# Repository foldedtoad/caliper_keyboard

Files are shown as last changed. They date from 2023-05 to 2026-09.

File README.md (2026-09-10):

# Caliper Keyboard - Digital Caliper Data Over Bluetooth (HOG)

## Overview
This poject's goal is to provide a remote interface to the various cheap Digital Calipers.  
This project's firmware is being developed on Zephyr Version 4.4.99.  
This is a major Zephyr upgrade and breaks backwards compatibility.

The Nordic nRF52 series Developemt Kits are the target hardware platform: PCA10056 (nRF52840dk_nrf52840) and a new custom board (**"nrf52840_caliper"**).
The nordic PCA10056 board was use for early development; there will be new board, nrf52840_caliper, specifically designed to be affixed to the back of a caliper.

Go to this project's [**Wiki**](https://github.com/foldedtoad/caliper_keyboard/wiki) page for more details.  

The image below shows size of the  **nrf52840_caliper** board, which is sized to fit on the back of calipers.  

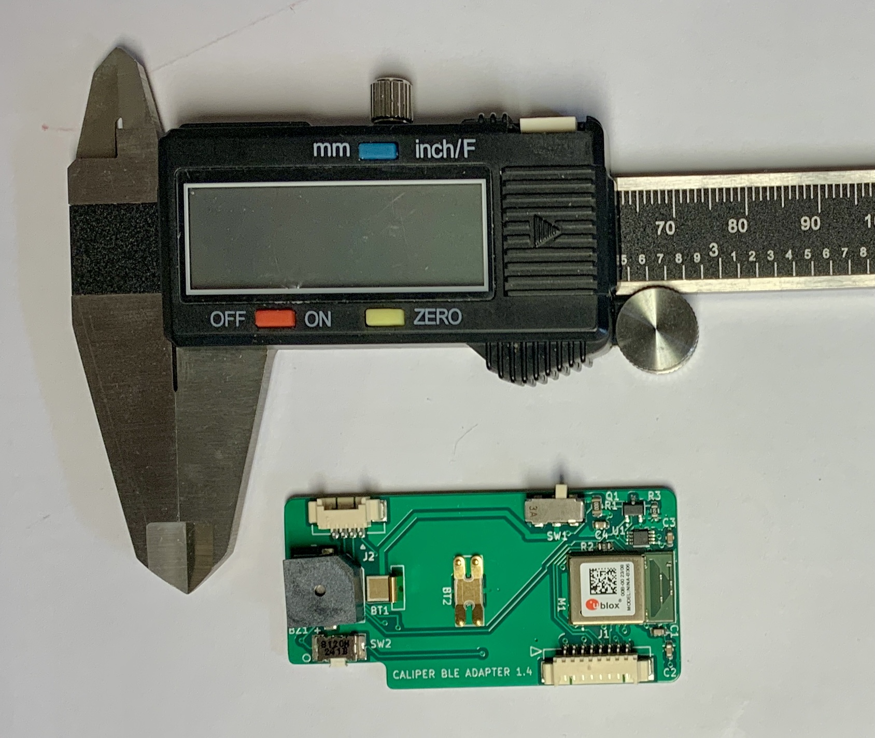
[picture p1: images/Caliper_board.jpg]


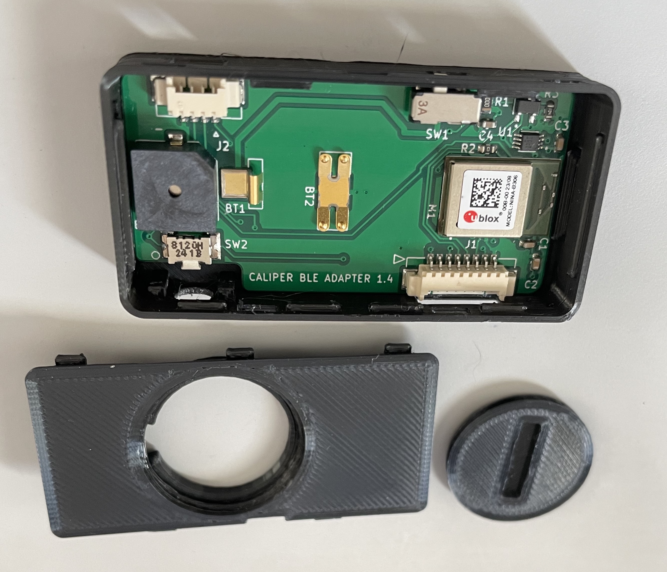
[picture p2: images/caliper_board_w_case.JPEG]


## Video of Caliper_Keyboard
There is a youtube video showing the caliper_keyboard attached to a cheap caliper: https://youtu.be/K_FeKUWlJKM

## How to Build
There are two easy methods to build the firmware.

### CMake Method
This build method use cmake directly, and doesn't use west or ninja.
1) cd to your caliper_keyboard root directory
2) run "./configure.sh"
3) cd to build directory
4) make

### West Method
1) cd to your caliper_keyboard root directory
2) rm -rf build
3) west build -b nrf52840_caliper

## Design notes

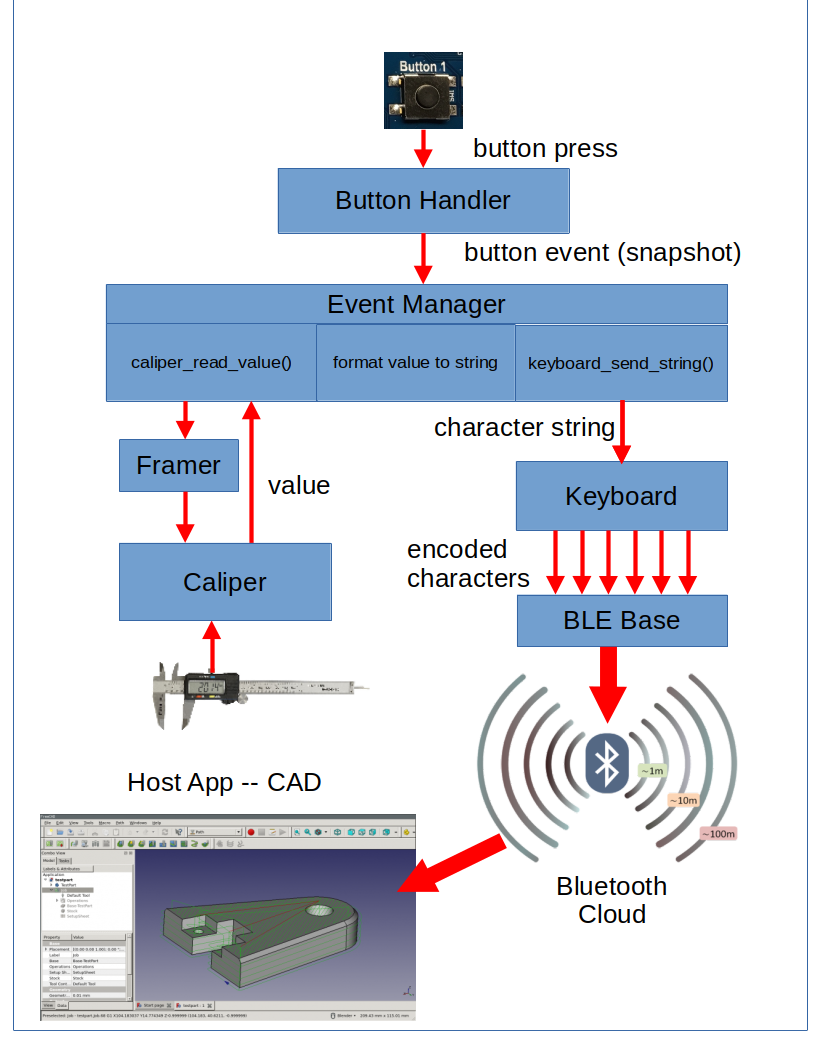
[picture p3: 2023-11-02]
images/caliper_keyboard_overview.png

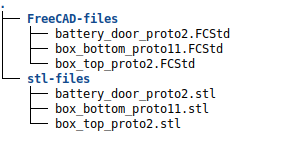
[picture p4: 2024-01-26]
images/freeCAD_STL.png

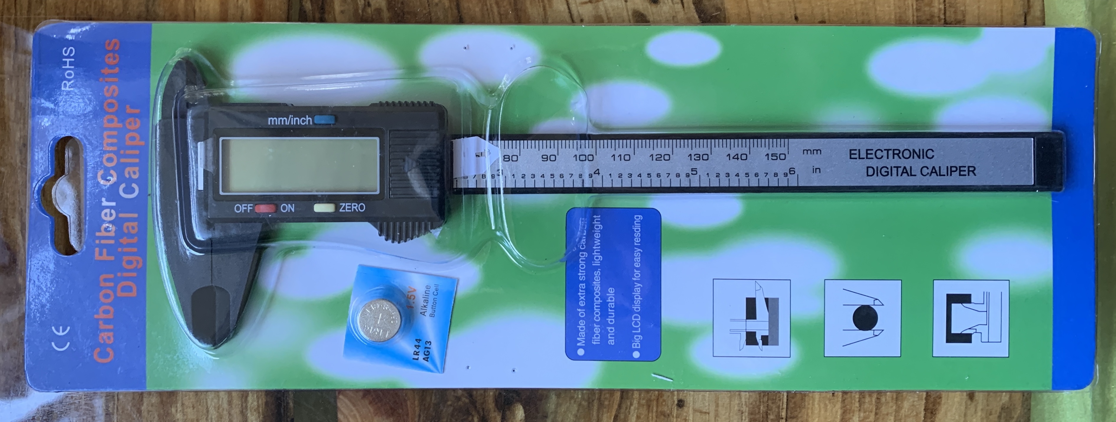
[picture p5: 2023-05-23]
images/caliper_product_package.jpg

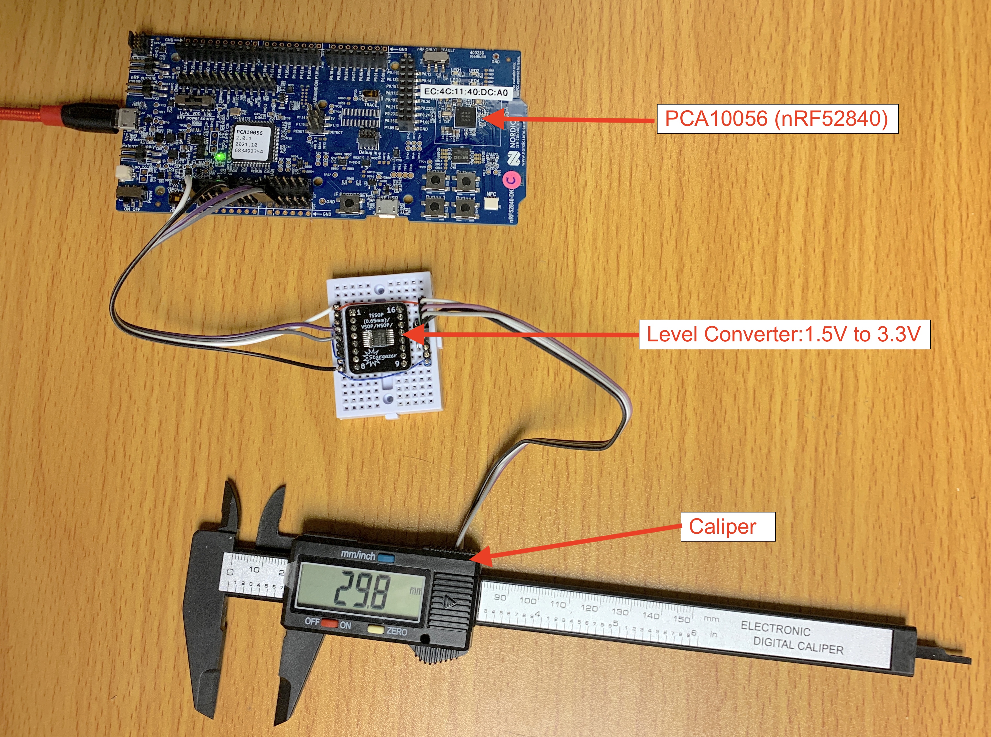
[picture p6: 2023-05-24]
images/Caliper_Keyboard_Prototype.JPG

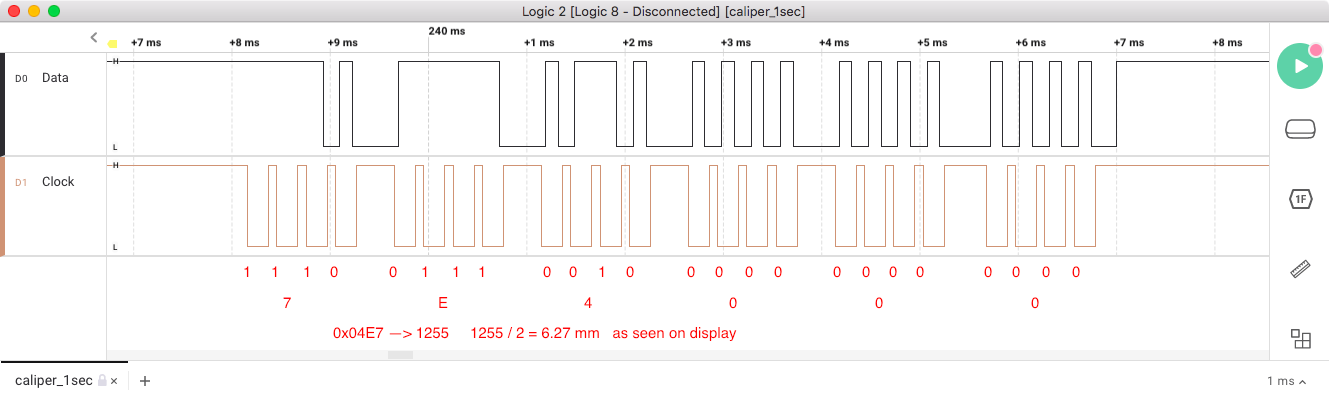
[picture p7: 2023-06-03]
images/caliper_frame.png

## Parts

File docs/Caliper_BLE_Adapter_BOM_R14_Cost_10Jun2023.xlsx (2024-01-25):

CALIPER BLE ADAPTER, BOM, REV 1.4, 09 JUNE 2023
DESCRIPTION | QTY | REF | FOOT PRINT | MFG | MFG PN | DK PN | UNIT $ | EXT $
Battery Contact Spring (Leaf) Multiple 1 Cell SMD (SMT) Tab | 1 | BT2 | 112 | Keystone Electronics | 112 | 36-112-ND | $0.300 | $0.300
Battery Contact Spring (Leaf) Multiple 1 Cell SMD (SMT) Tab | 1 | BT1 | 110 | Keystone Electronics | 110 | 36-110-ND | $0.300 | $0.300
Buzzers Indicator, Internally Driven Magnetic 3 V 30mA 2.7kHz 80dB @ 3V, 10cm Surface Mount Solder Pads | 1 | BZ1 |  | CU Devices | CMI-9705-0380-SMT-TR | CMI-9705-0380-SMT-TR | $2.080 | $2.080
4.7 µF ±20% 10V Ceramic Capacitor X5R 0603 (1608 Metric) | 1 | C2 | C0603 | YAGEO | CC0603MRX5R6BB475 | 311-1820-1-ND | $0.114 | $0.114
0.1 µF ±10% 10V Ceramic Capacitor X7R 0603 (1608 Metric) | 2 | C1, C3 | C0603 | YAGEO | CC0603KRX7R6BB104 | 311-4055-1-ND | $0.070 | $0.140
1 µF -20%, +80% 10V Ceramic Capacitor Y5V (F) 0603 (1608 Metric) | 1 | C4 | C0603 | YAGEO | CC0603ZRY5V6BB105 | 311-1357-1-ND | $0.061 | $0.061
Connector Header Surface Mount, Right Angle 8 position 0.049" (1.25mm) | 1 | J1 | 0532610871 | MOLEX | 0532610871 | WM7626CT-ND | $0.930 | $0.930
Connector Header Surface Mount, Right Angle 4 position 0.049" (1.25mm) | 1 | J2 | 532610471 | MOLEX | 532610471 | WM7622CT-ND | $0.720 | $0.720
Connector Header Surface Mount, Right Angle 8 position 0.100" (2.54mm) | 0 | J3 | DO NOT POPULATE | Harwin Inc. | M20-8890845R | 952-M20-8890845RCT-ND | $1.540 | $0.000
Bluetooth Bluetooth v5.0 Transceiver Module 2.4GHz Integrated, Trace Surface Mount | 1 | M1 |  | UBLOX | NINA-B306-00B | 672-NINA-B306-00BCT-ND | $14.350 | $14.350
N-Channel 20 V 3A (Ta) 1.4W (Ta) Surface Mount SOT-23-3 | 1 | Q1 |  | Alpha & Omega Semiconductor Inc. | AO3414 | 785-1009-1-ND | $0.470 | $0.470
0 Ohms Jumper Chip Resistor 0805 (2012 Metric) Moisture Resistant Thick Film | 1 | R1 | R0805 | YAGEO | RC0805JR-070RL | 311-0.0ARCT-ND | $0.028 | $0.028
0 Ohms Jumper Chip Resistor 0603 (1608 Metric) Moisture Resistant Thick Film | 1 | R2 | R0603 | YAGEO | RC0603FR-070RL | 311-0.0HRCT-ND | $0.018 | $0.018
100 kOhms ±5% 0.1W, 1/10W Chip Resistor 0603 (1608 Metric) Moisture Resistant Thick Film | 1 | R3 | R0603 | YAGEO | RC0603JR-10100KL | YAG2294CT-ND | $0.015 | $0.015
Slide Switch DPDT Surface Mount, Right Angle | 1 | SW1 | CL-SB-22A-12T | Nidec Copal Electronics | CL-SB-22A-12T | 563-1341-1-ND | $1.790 | $1.790
Tactile Switch SPST-NO Side Actuated Surface Mount, Right Angle | 1 | SW2 | KSS241GLFS | C&K | KSS241GLFS | 401-1099-1-ND | $0.650 | $0.650
Voltage Level Translator Bidirectional 1 Circuit 2 Channel 380Mbps 8-VSSOP | 1 | U1 | 8VSSOP | Texas Instruments | SN74AXC2T45DCUR | 296-SN74AXC2T45DCURCT-ND | $0.950 | $0.950
TOTAL |  |  |  |  |  |  |  | $22.916

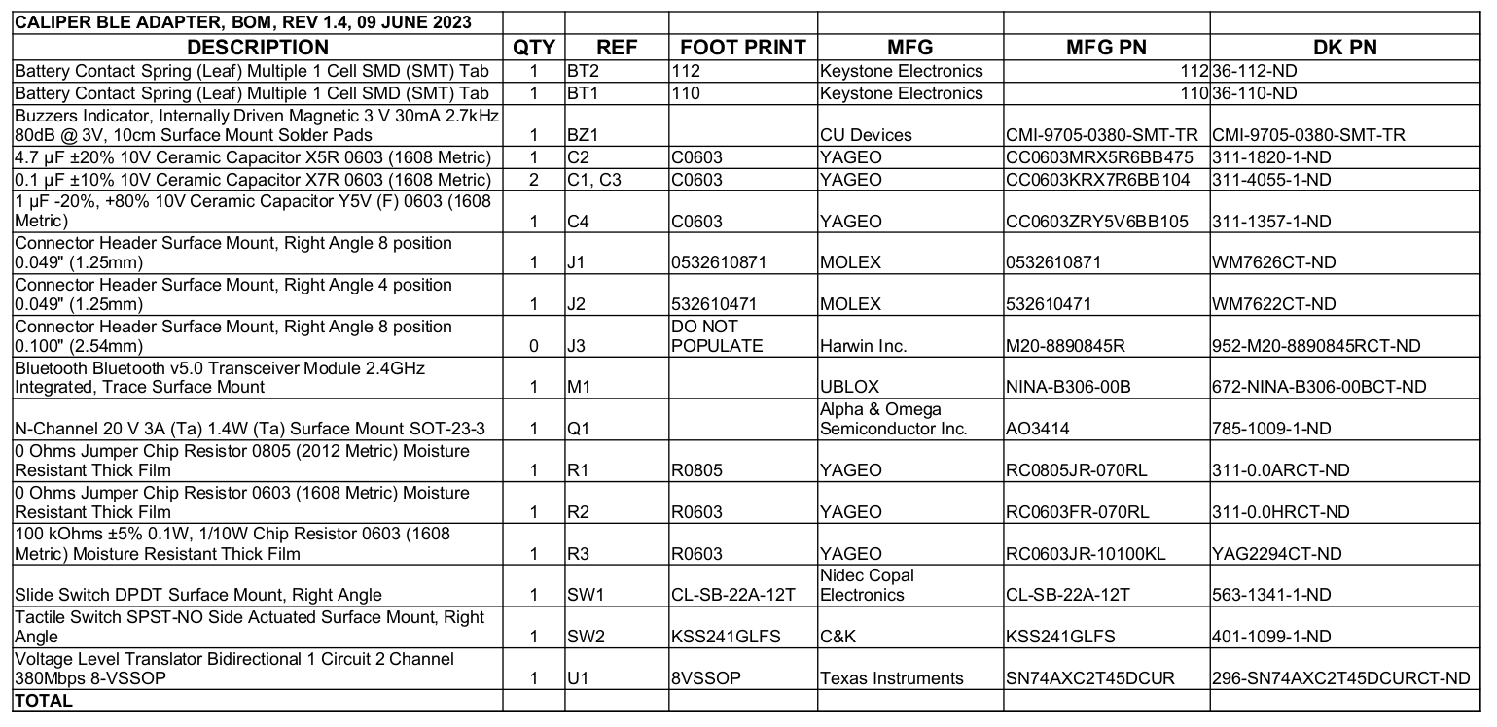
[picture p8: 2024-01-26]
images/caliper_bom.png

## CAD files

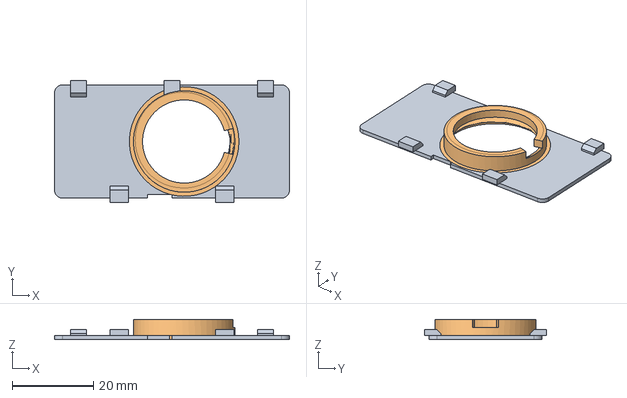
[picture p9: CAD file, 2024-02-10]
docs/Caliper_Case/FreeCAD-files/battery_top_wBat_assy3.FCStd
57.9 x 30.0 x 5.00 mm
box_top_proto4_bat_001
battery_compartment_proto4_001

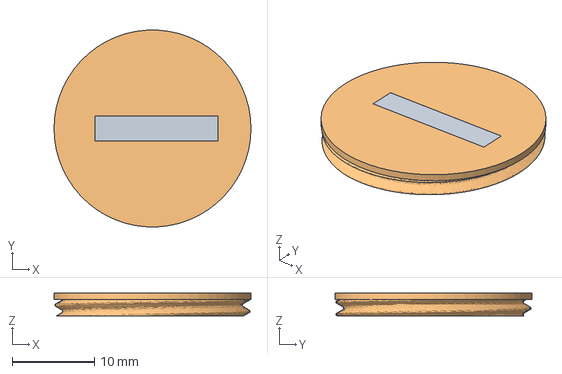
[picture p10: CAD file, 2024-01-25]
docs/Caliper_Case/FreeCAD-files/battery_door_proto2.FCStd
24.0 x 24.0 x 2.75 mm

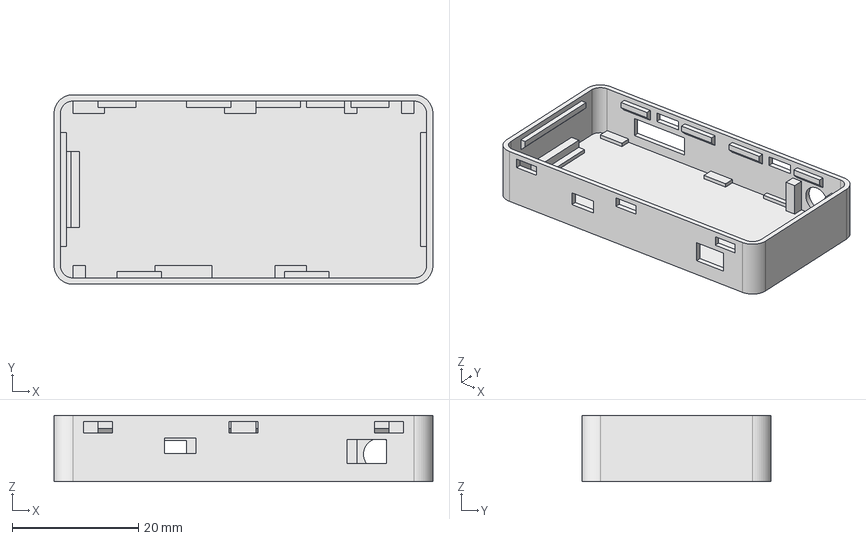
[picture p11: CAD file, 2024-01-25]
docs/Caliper_Case/FreeCAD-files/box_bottom_proto11.FCStd
60.0 x 30.0 x 10.5 mm

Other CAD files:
docs/Caliper_Case/stl-files/battery_door_proto2.stl
docs/Caliper_Case/stl-files/battery_top_wBat_assy3.stl
docs/Caliper_Case/stl-files/box_bottom_proto11.stl

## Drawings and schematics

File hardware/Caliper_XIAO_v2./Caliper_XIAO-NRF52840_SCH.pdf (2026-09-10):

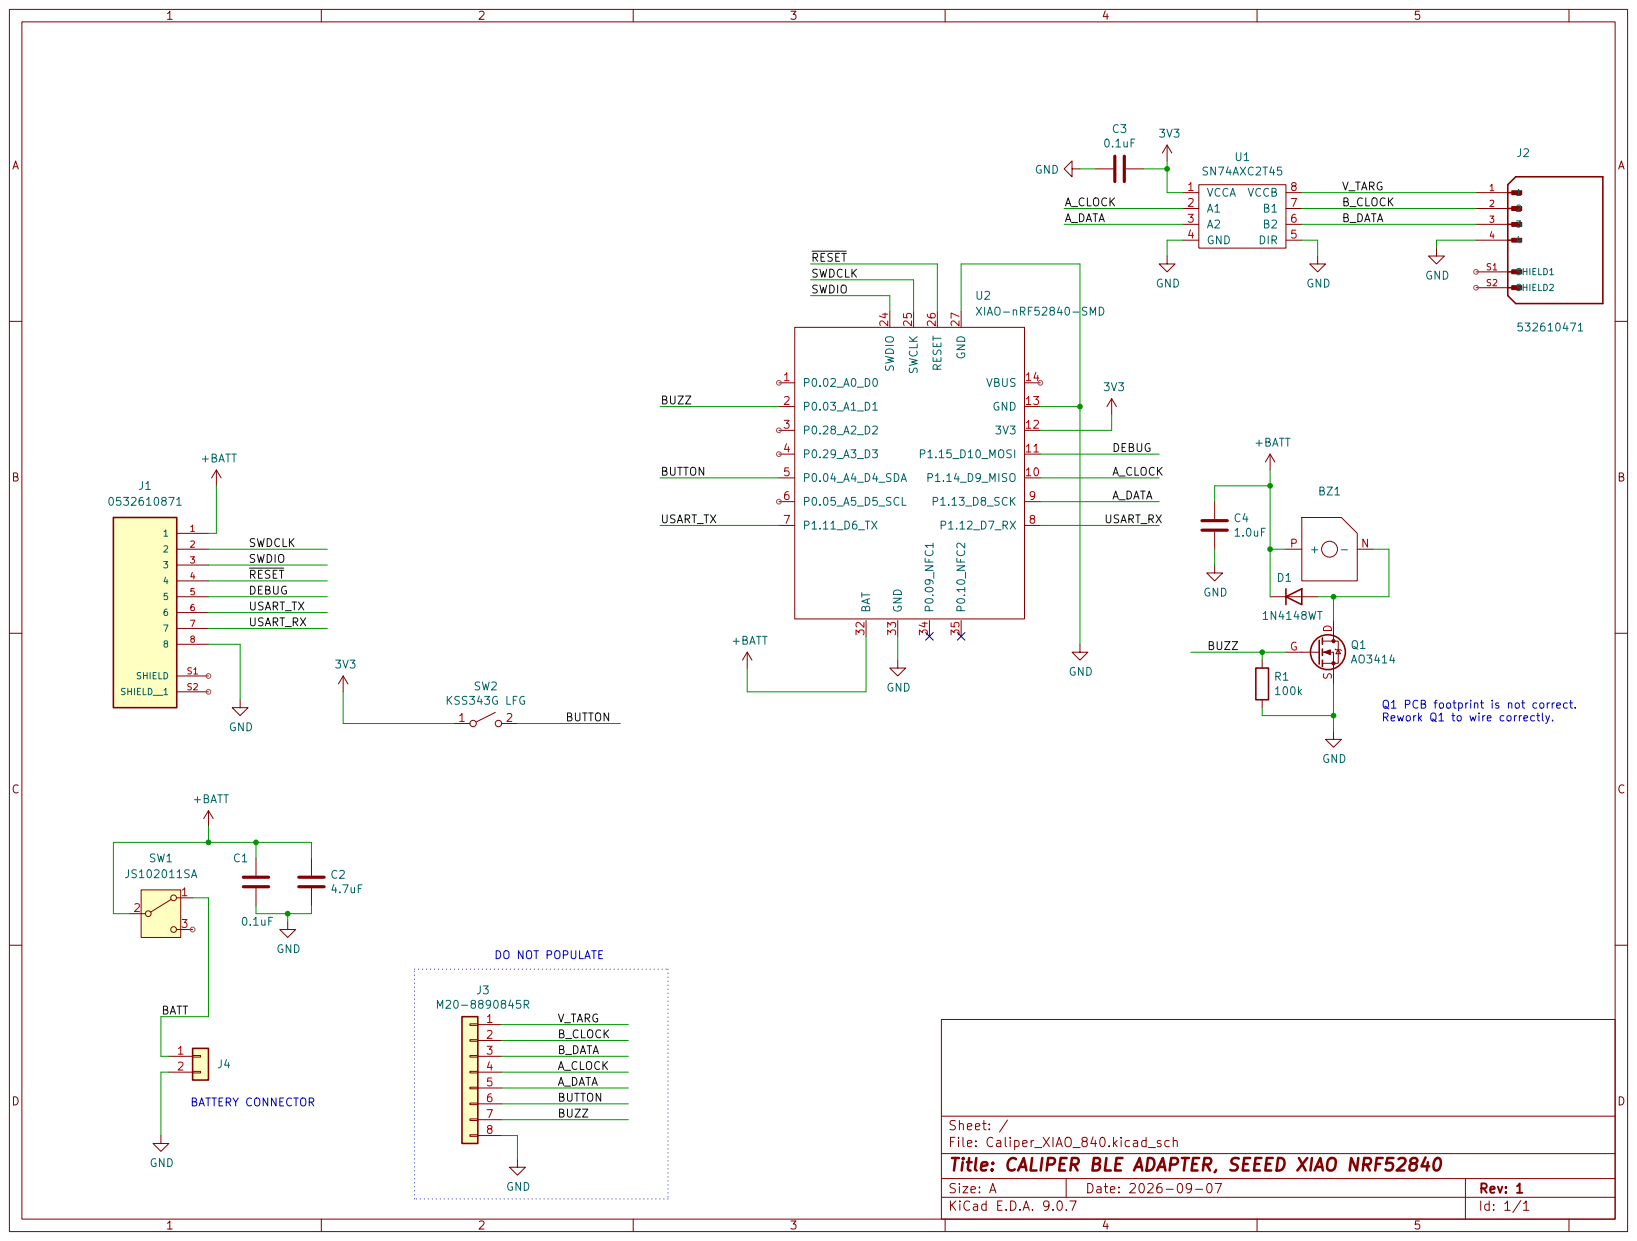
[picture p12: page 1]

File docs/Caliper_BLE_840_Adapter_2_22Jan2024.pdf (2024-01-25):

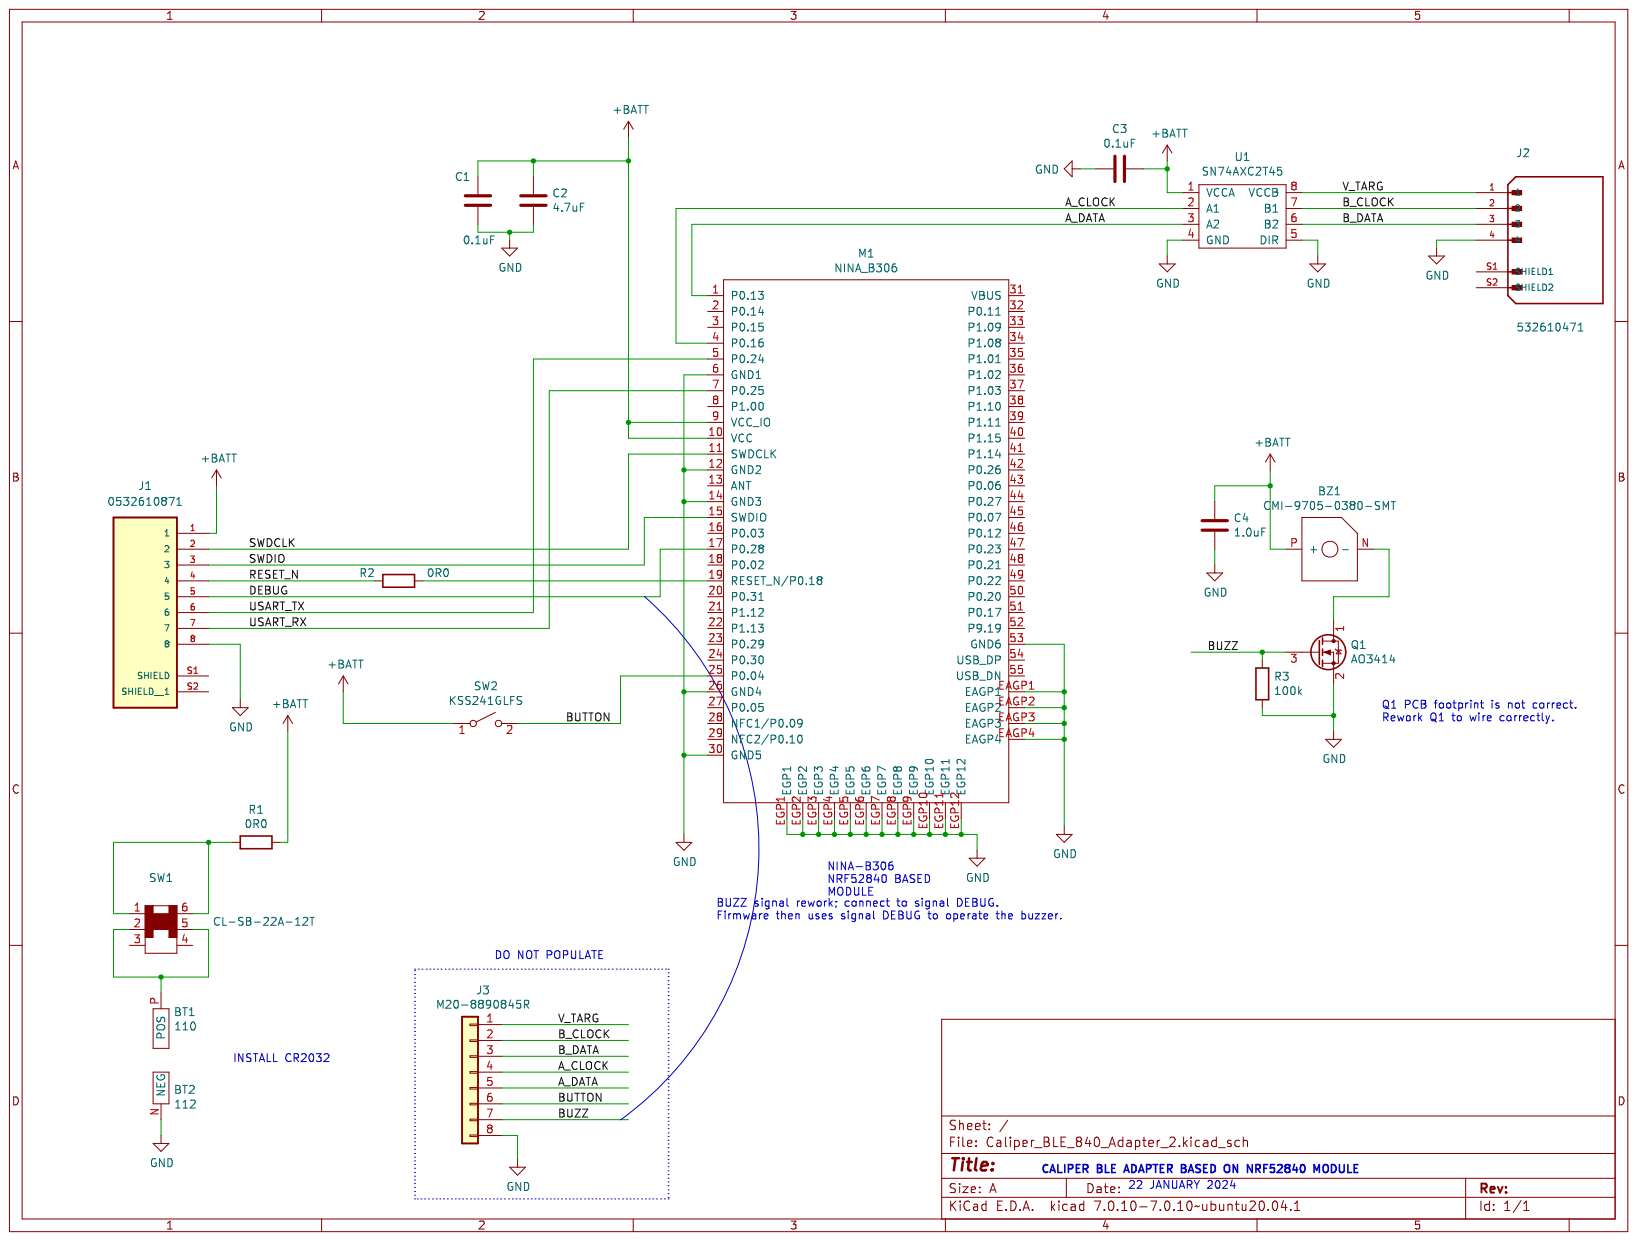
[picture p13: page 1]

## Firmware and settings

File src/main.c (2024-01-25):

/* 
 *  main.c - Application main entry point 
 */
#include <stdio.h>
#include <stdlib.h>
#include <zephyr/kernel.h>
#include <zephyr/sys/printk.h>
#include <zephyr/drivers/hwinfo.h> 

#include "events.h"
#include "watchdog.h"
#include "shell.h"
#include "battery.h"
#include "app_uicr.h"
#include "ble_base.h"
#include "ble_alt.h"
#include "framer.h"
#include "buzzer.h"

#include <zephyr/logging/log.h>
LOG_MODULE_REGISTER(main, 3);

#define STACKSIZE 1024
#define PRIORITY 7

/*---------------------------------------------------------------------------*/
/*                                                                           */
/*---------------------------------------------------------------------------*/

typedef struct {
    uint32_t code;
    char *   text;
} reason_t; 

static reason_t reasons[] = {
    { RESET_PIN,            "Reset Pin"     },  // BIT(0)
    { RESET_SOFTWARE,       "Software"      },  // BIT(1)
    { RESET_BROWNOUT,       "Brown Out"     },  // BIT(2)
    { RESET_POR,            "POR"           },  // BIT(3)
    { RESET_WATCHDOG,       "Watchdog"      },  // BIT(4)
    { RESET_DEBUG,          "Debug"         },  // BIT(5)
    { RESET_SECURITY,       "Security"      },  // BIT(6)
    { RESET_LOW_POWER_WAKE, "Low Pwr Wake"  },  // BIT(7)
    { RESET_CPU_LOCKUP,     "CPU Lockup"    },  // BIT(8)
    { RESET_PARITY,         "Parity"        },  // BIT(9)
    { RESET_PLL,            "PLL"           },  // BIT(10)
    { RESET_CLOCK,          "Clock"         },  // BIT(11)
    { RESET_HARDWARE,       "Hardware"      },  // BIT(12)
    { RESET_USER,           "User"          },  // BIT(13)
    { RESET_TEMPERATURE,    "Temperature"   },  // BIT(14)
};
#define REASONS_COUNT (sizeof(reasons)/sizeof(reason_t))

static bool alt_ble_app = false;

/*---------------------------------------------------------------------------*/
/*                                                                           */
/*---------------------------------------------------------------------------*/
static char * get_reason_text(uint32_t reset_reason)
{
    static char string[48];

    string[0] = 0;

    for(int i=0; i < REASONS_COUNT; i++) {
        if (reset_reason & reasons[i].code) {
            reset_reason &= ~reasons[i].code;
            strcat(string, reasons[i].text);
            if (reset_reason)
                strcat(string, ", ");
        }
    }
    return (char*) &string;
}

/*---------------------------------------------------------------------------*/
/*                                                                           */
/*---------------------------------------------------------------------------*/
bool is_alt_running(void)
{
    return alt_ble_app;
}

/*---------------------------------------------------------------------------*/
/*                                                                           */
/*---------------------------------------------------------------------------*/
void main_thread(void * id, void * unused1, void * unused2)
{
    uint32_t reset_reason = 0;

    hwinfo_get_reset_cause(&reset_reason);
    hwinfo_clear_reset_cause();

    LOG_INF("*** Reset Reason: (0x%02X) %s", 
            reset_reason, get_reason_text(reset_reason));

    app_uicr_init();

    buttons_init();

    if (boot_button_state() == BOOT_OPTIONS_ALTERNATE) {
        LOG_INF("Alternate BLE service starting...");
        alt_ble_app = true;

        ble_alt_init();
    }
    else {
        LOG_INF("Primary BLE service starting...");        
        ble_base_init();
    }

    battery_init();

    framer_init();

    buzzer_init();

    caliper_init();

    events_init();

    caliper_shell_init();

    watchdog_init();   /* watchdog_init never returns */
}


K_THREAD_DEFINE(main_id, STACKSIZE, main_thread,
                NULL, NULL, NULL, PRIORITY, 0, 0);

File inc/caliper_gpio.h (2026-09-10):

/*
 * Copyright (c) 2023 Callender-Consulting
 *
 * SPDX-License-Identifier: Apache-2.0
 *
 *   caliper_gpio.h
 */
#ifndef __CALIPER_GPIO_H
#define __CALIPER_GPIO_H

/*---------------------------------------------------------------------------*/
/*  Pins related to caliper                                                  */
/*---------------------------------------------------------------------------*/

#define CLOCK_NODE      DT_ALIAS(caliper_clock)
#define CLOCK           DT_GPIO_PIN(DT_ALIAS(caliper_clock), gpios)
#define CLOCK_PORT      DT_LABEL(DT_PHANDLE_BY_IDX(DT_ALIAS(caliper_clock), gpios, 0))
#define CLOCK_FLAGS     DT_PHA_BY_IDX(DT_ALIAS(caliper_clock), gpios, 0, flags)
#define CLOCK_LABEL     DT_PROP(DT_ALIAS(caliper_clock), label)

#define DATA_NODE       DT_ALIAS(caliper_data)
#define DATA            DT_GPIO_PIN(DT_ALIAS(caliper_data), gpios)
#define DATA_PORT       DT_LABEL(DT_PHANDLE_BY_IDX(DT_ALIAS(caliper_data), gpios, 0))
#define DATA_FLAGS      DT_PHA_BY_IDX(DT_ALIAS(caliper_data), gpios, 0, flags)
#define DATA_LABEL      DT_PROP(DT_ALIAS(caliper_data), label)

#define BUZZER_NODE     DT_ALIAS(caliper_buzzer)
#define BUZZER          DT_GPIO_PIN(DT_ALIAS(caliper_buzzer), gpios)
#define BUZZER_PORT     DT_LABEL(DT_PHANDLE_BY_IDX(DT_ALIAS(caliper_buzzer), gpios, 0))
#define BUZZER_FLAGS    DT_PHA_BY_IDX(DT_ALIAS(caliper_buzzer), gpios, 0, flags)
#define BUZZER_LABEL    DT_PROP(DT_ALIAS(caliper_buzzer), label)
#define BUZZER_PWM_NODE DT_ALIAS(buzzer0)

#endif  /* __CALIPER_GPIO_H */

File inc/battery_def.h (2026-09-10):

/*
 * Copyright (c) 2019 Nordic Semiconductor ASA
 *
 * SPDX-License-Identifier: LicenseRef-Nordic-5-Clause
 */

const struct {} battery_def_include_once;

#define BATTERY_MEAS_ADC_INPUT              NRF_SAADC_INPUT_VDD  //HDIV5
#define BATTERY_MEAS_ADC_GAIN               ADC_GAIN_1_6
#define BATTERY_MEAS_VOLTAGE_GAIN           6

#define BATTERY_MEAS_POLL_INTERVAL_MS       60000
#define BATTERY_MEAS_MAX_LEVEL              3200
#define BATTERY_MEAS_MIN_LEVEL              2000

#define VOLTAGE_TO_SOC_DELTA                10

/* 
 * Converting measured battery voltage[mV] to State of Charge[%].
 * First element corresponds to BATTERY_MIN_LEVEL.
 * Each element is VOLTAGE_TO_SOC_DELTA higher than previous.
 * Defined separately for every configuration.
 */
static const uint8_t battery_voltage_to_soc[] = 
{
  // 0   1   2   3   4   5   6   7   8   9 
  //======================================== 
     0,  0,  1,  1,  1,  1,  1,  1,  1,  1,  // 00
     1,  1,  1,  1,  1,  1,  1,  1,  1,  2,  // 10
     2,  2,  2,  2,  2,  2,  2,  2,  3,  3,  // 20
     3,  3,  3,  3,  3,  4,  4,  4,  4,  4,  // 30
     4,  5,  5,  5,  6,  6,  7,  7,  8,  8,  // 40
     9,  9, 10, 11, 12, 13, 13, 14, 15, 16,  // 50
    18, 19, 22, 25, 28, 32, 36, 40, 44, 47,  // 60
    51, 53, 56, 58, 60, 62, 64, 66, 67, 69,  // 70
    71, 72, 74, 76, 77, 79, 81, 82, 84, 85,  // 80
    85, 86, 86, 86, 87, 88, 88, 89, 90, 91,  // 90
    91, 92, 93, 94, 95, 96, 97, 98, 99, 100, // 100
    100
};

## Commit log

2023-06-02 add reset reason support
    [main.c]
2023-06-04 configure UART pins via pinctrl
2023-06-22 add config for nrf52840_caliper board
2023-09-24 bring-up on nrf52840_caliper board
2023-09-24 debound snapshot switch (sw0)
2023-09-28 add battery monitoring support
2023-10-01 more battery work
2023-10-02 revert caliper power test
    [caliper.c]
2023-10-11 change priority for caliper thread
2023-10-18 Framer (#4)
    * start of framer
    * add interframe gap detection
    ---------
2023-10-18 dynamically update power state
2023-10-29 Buzzer (#5)
    * start of buzzer support
    * turn off temp_save
    * work on buzzer
    * buzzer work
    * more buzzer work.
    * minor clean-up
    * remove redundant code
    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
    [caliper_gpio.h, framer.c, main.c]
2023-10-30 add remote button
2023-11-05 fix DTS for nrf52840/PCA10056 board
2024-01-25 add more images and docs
    [Caliper_BLE_Adapter_BOM_R14_Cost_10Jun2023.xlsx]
2024-01-25 Add files via upload
    Add FreeCAD and STL files for printing case.
    [battery_door_proto2.FCStd, battery_door_proto2.stl, box_bottom_proto11.FCStd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]
2024-02-10 update case-related files
    [box_top_proto2.FCStd, box_top_proto2.stl]
2024-02-10 update 3d print case files
    [battery_top_wBat_assy3.FCStd, battery_top_wBat_assy3.stl]
2026-09-10 Buzzer pwm (#8)
    * upgrade to Zephyr V4.4.99
    * update README.md
    * route Buzzer to P0.03
    * support for new buzzer with PWM
    * update DTS
    * add new buzzer support
    * add Caliper hardware section
    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
    [Caliper_XIAO_840-B_Cu.gbr, Caliper_XIAO_840-B_Mask.gbr, Caliper_XIAO_840-B_Paste.gbr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]
2026-10-12 add xiao_caliper board definition
